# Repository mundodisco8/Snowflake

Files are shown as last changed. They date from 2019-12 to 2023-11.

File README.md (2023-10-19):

View this project on [CADLAB.io](https://cadlab.io/project/26393).

# Snowflake

A Snowflake Christmas decoration.
<p align="middle">
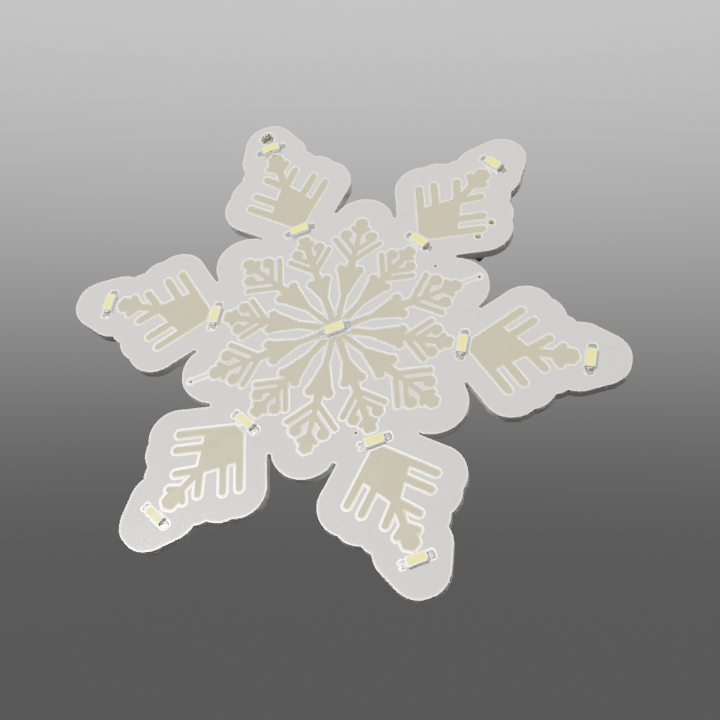
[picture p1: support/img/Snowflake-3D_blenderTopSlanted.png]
  
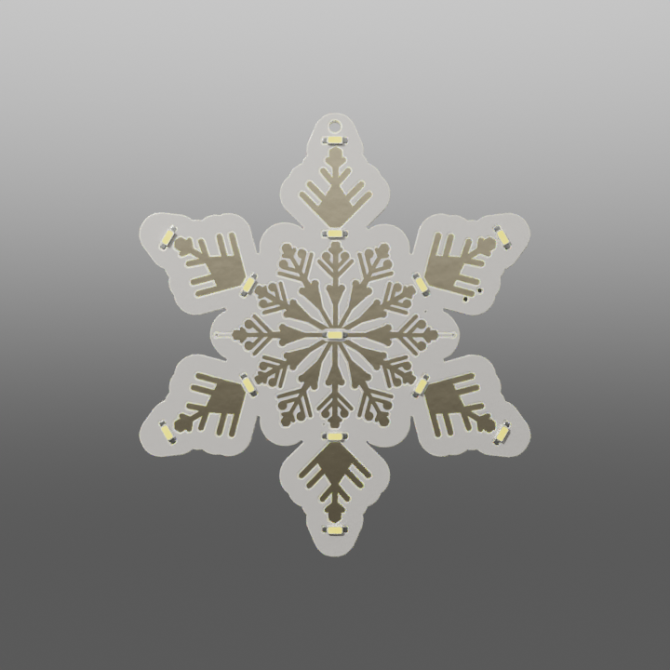
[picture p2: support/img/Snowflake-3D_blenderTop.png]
  
</p>

<p align="middle">
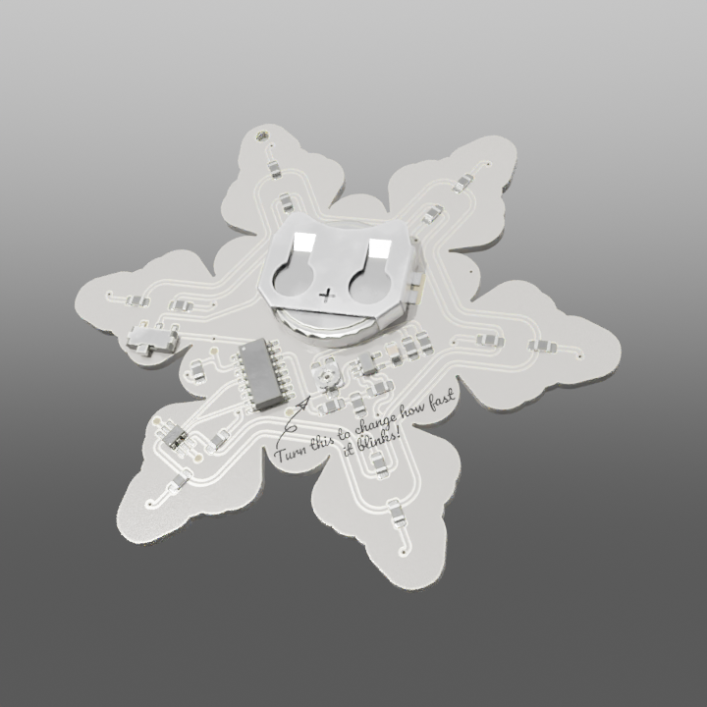
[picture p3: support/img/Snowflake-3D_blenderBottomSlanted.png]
  
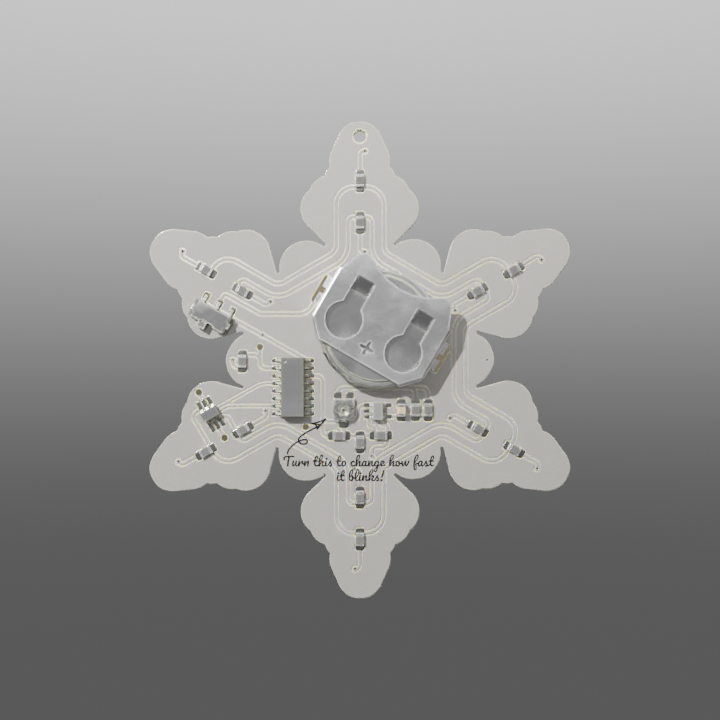
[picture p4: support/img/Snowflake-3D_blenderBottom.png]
  
</p>

Just a design exercise, aiming to get a hand-solderable board (although a bit challenging) that blinks its LEDs without using a microcontoller. I guess you can call it a mix of digital and analogue electronics, because the main trigger is a binary counter that is fed by a clock generated with an opamp in astable multivibrator config.

## Outputs

The outputs of this project can be found in the Releases area.

## Documentation

### Design Intention

You can find the design document in the [docs section](docs/Design%20Justification.ipynb), as a Jupyter notebook, or [better rendered here](https://mundodisco8.github.io/Snowflake), as a static rendering of the jupyter notebooks. For an interactive session, you can launch it on Binder if you want to play with the sliders.



You might even want to clone this repo and get your hands dirty. If you do, remember to create a virtual environment and install all the requirements.

```bash
python -m venv venv
venv/Scripts/Activate.bat # or source venv/bin/activate in Linux/Mac
python -m pip install -r requirements.txt
```

### Other bits and bobs

In the LTSpice folder you will find the circuits used on the Jupyter notebook to guess the current consumption as the battery discharges.

The `docs` folder also contains a couple of Excel spreadsheets I used to calculate some stuff, but they are not that interesting.

## Support Folder

The support folder contains random stuff that I needed at some point, mostly graphics.

I nicked the graphics from [here](https://svgsilh.com/image/2960229.html), which in turn is a variation of [this](https://pixabay.com/illustrations/snowflake-pattern-decor-decorative-2960229/).

## Running the CI/CD locally

The Release section only contains the artifacts of some hand-picked commits. Github Actions run on each commit on master, but the artifacts generated there have a self-life and get deleted after 15 days, I think. If you want, you can run the CICD pipeline locally.

```bash
# on the folder containing the project
# pull the KiBot image
docker pull ghcr.io/inti-cmnb/kicad7_auto_full:dev
# create a container named KiBotSnowDev, attaching the current folder as /Snowflake
docker run -it --name KiBotSnowDev -v .:/SnowFlake --entrypoint=/bin/bash ghcr.io/inti-cmnb/kicad7_auto_full:dev
# Now you are attached to the container
kibot -c ArtifactCreation.kibot.yaml -e hardware/Snowflake.kicad_sch -b hardware/Snowflake.kicad_pcb
```

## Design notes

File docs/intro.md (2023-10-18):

# Snowflake Interactive Documentation

This Jupyter Book contains the documentation of the project.

Check out the content pages bundled with this sample book to see more.

```{tableofcontents}
```

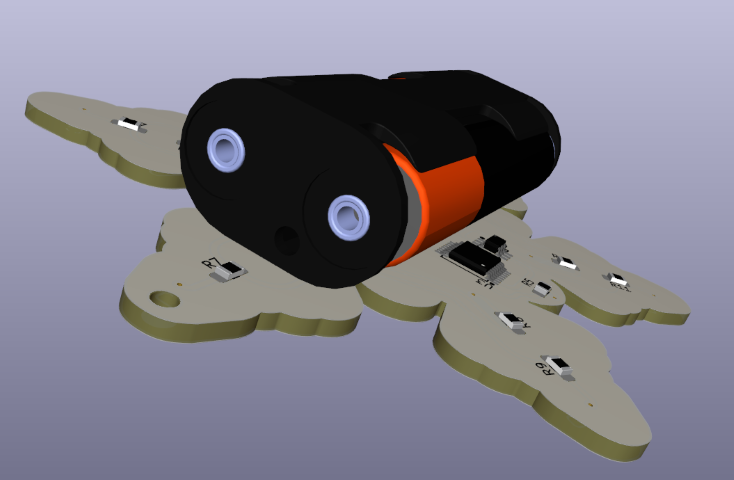
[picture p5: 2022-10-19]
img/AAA_On_PCB.png

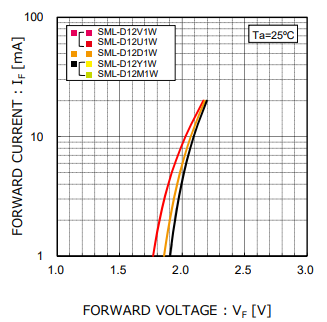
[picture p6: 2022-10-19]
img/Yellow_LED_Bias.png

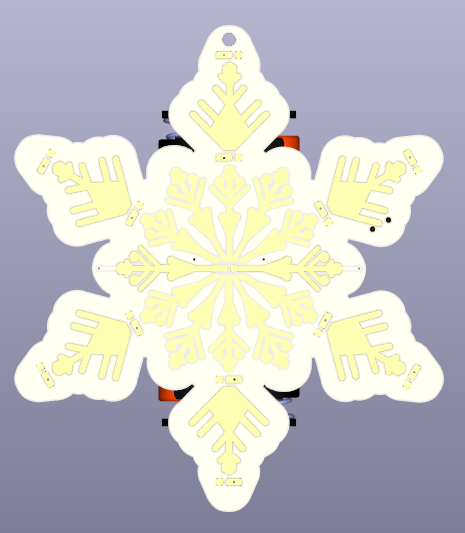
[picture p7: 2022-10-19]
img/AAA_On_PCB_Front.png

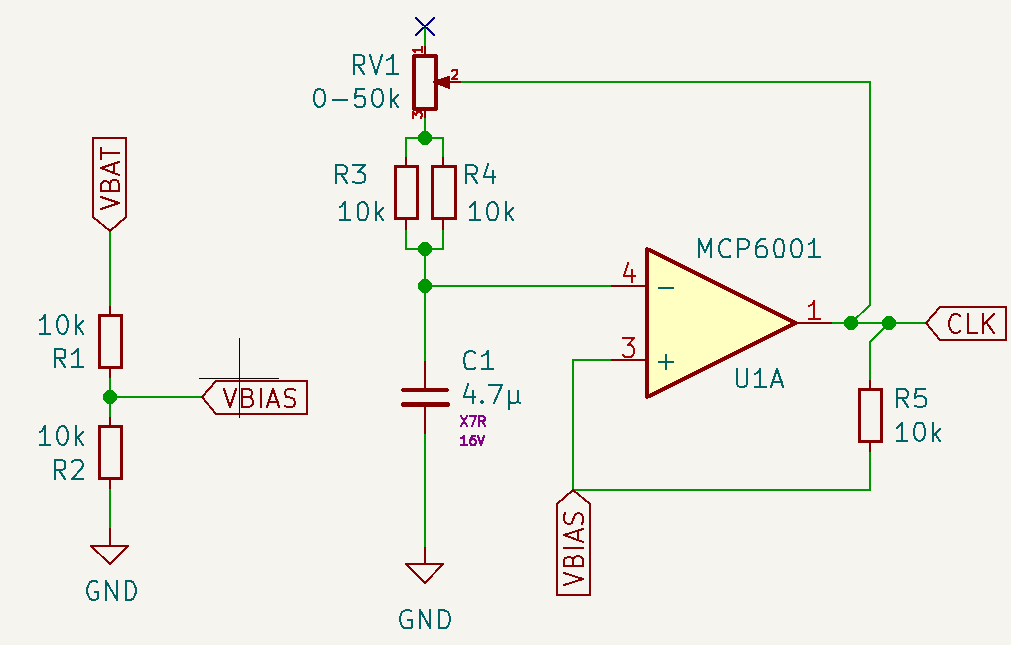
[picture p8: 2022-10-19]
img/Clock_With_Values.png

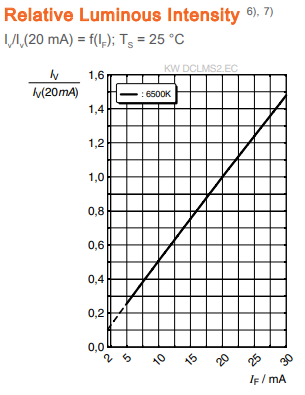
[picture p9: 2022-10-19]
img/KW_DCLMS2_LightvsCurr.png

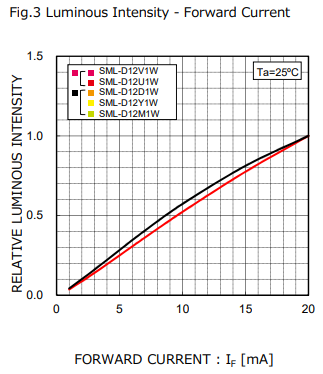
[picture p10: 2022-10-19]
img/Yellow_LED_LightvsCurr.png

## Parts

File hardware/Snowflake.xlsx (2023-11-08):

Prj: | Snowflake |  |  |  |  |  |  | Board Qty: | 12
Co.: |  |  |  |  |  |  |  | Unit Cost: | $6.97
Prj date: | 08/11/2023 13:36:20 |  |  |  |  |  |  | Total Cost: | $83.67 |  |  |  |  | $76.85 | 11 of 11 parts found
$ date: | 2023-11-08 13:36:46
Global Part Info |  |  |  |  |  |  |  |  |  | Digi-Key
Refs | Value | Footprint | Manf | Manf# | Tengo | Contingency | Qty | Unit$ | Ext$ | Avail | Purch | Unit$ | MOQ | Ext$ | Cat#
BT1 | CR2032 | CR2032_Keystone_3034 | Keystone Electronics | 3034 | 2 | 1 | 12 | $0.370 | $4.44 | 22324 | 11 | $0.370 | 1 | $4.07 | 36-3034-ND (https://www.digikey.com/en/products/detail/keystone-electronics/3034/4499289)
C1 | 4.7μ | 0805 | Murata | GRM21BR71C475KE51K | 12 |  | 12 |  |  | 86626 | 0 | $0.000 | 1 | $0.00 | 490-GRM21BR71C475KE51KCT-ND (https://www.digikey.com/en/products/detail/murata-electronics/GRM21BR71C475KE51K/8346263)
D1-D13 | White | 3014 | Osram | KWDCLMS2.EC-CXCZ-4L7M (https://dammedia.osram.info/media/resource/hires/osram-dam-16984996/KW%20DCLMS2.EC_EN.pdf) | 25 | 10 | 156 | $0.095 | $14.80 | 1122 | 141 | $0.095 | 1 | $13.38 | 475-KWDCLMS2.EC-CXCZ-4L7M-1-20-R18CT-ND (https://www.digikey.com/en/products/detail/ams-osram-usa-inc/KW-DCLMS2-EC-CXCZ-4L7M-1-20-R18/13679454)
Q1 | DMN2004DMK | SOT23-6 | Diodes Inc. | DMN2004DMK (https://www.diodes.com/assets/Datasheets/ds30937.pdf~) | 6 | 5 | 12 | $0.357 | $4.28 | 204723 | 11 | $0.357 | 1 | $3.93 | DMN2004DMKDICT-ND (https://www.digikey.com/en/products/detail/diodes-incorporated/DMN2004DMK-7/1287178)
R1-R5 | 10k | 0805 | Yageo | AF0805FR-0710KL | 50 | 10 | 60 | $0.054 | $3.24 | 26454 | 20 | $0.054 | 1 | $1.08 | 13-AF0805FR-0710KLCT-ND (https://www.digikey.com/en/products/detail/yageo/AF0805FR-0710KL/5901208)
R6-R18 | 56 | 0805 | Yageo | RC0805FR-1056RL | 28 | 10 | 156 | $0.013 | $1.98 | 21690 | 138 | $0.013 | 1 | $1.75 | 13-RC0805FR-1056RLCT-ND (https://www.digikey.com/en/products/detail/yageo/RC0805FR-1056RL/14286374)
RV1 | 0-50k | Potentiometer_TC33X-2-204E_NoSilk | Bourns Inc. | TC33X-2-503E (https://www.bourns.com/docs/Product-Datasheets/TC33.pdf) | 0 | 3 | 12 | $0.273 | $3.28 | 4117 | 15 | $0.273 | 1 | $4.10 | TC33X-503ECT-ND (https://www.digikey.com/en/products/detail/bourns-inc/TC33X-2-503E/612862)
SW1 | SPDT | Slider_Switch_C&K_AYZ0102AGRLC_SPDT_RightAngle_NoSilk | C&K | AYZ0102AGRLC (https://www.ckswitches.com/media/1431/ayz.pdf) | 2 | 1 | 12 | $1.204 | $14.45 | 9370 | 11 | $1.204 | 1 | $13.24 | 401-2012-1-ND (https://www.digikey.com/en/products/detail/c-k/AYZ0102AGRLC/1640108)
U1 | MCP6001T | SOT23-6 | Microchip | MCP6001T-I/OT (https://ww1.microchip.com/downloads/en/DeviceDoc/MCP6001-1R-1U-2-4-1-MHz-Low-Power-Op-Amp-DS20001733L.pdf) | 0 | 3 | 12 | $0.300 | $3.60 | 34720 | 15 | $0.300 | 1 | $4.50 | MCP6001T-I/OTCT-ND (https://www.digikey.com/en/products/detail/microchip-technology/MCP6001T-I-OT/551760)
U2#1 | HEF4017BT - p1/2 | 16-SOIC, 3.9x9.9mm, Pitch 1.27mm | Nexperia | HEF4017BT (https://assets.nexperia.com/documents/data-sheet/HEF4017B.pdf) | 1 | 3 | 12 |  |  | NonStk | 14 | MOQ=2500 | 2500 |  | 1727-HEF4017BT-Q100JTR-ND (https://www.digikey.com/en/products/detail/nexperia-usa-inc/HEF4017BT-Q100J/5169993)
U2#2 | HEF4017BT - p2/2 | 16-SOIC, 3.9x9.9mm, Pitch 1.27mm | Nexperia | 653 (https://assets.nexperia.com/documents/data-sheet/HEF4017B.pdf) | 1 |  | 12 | $2.800 | $33.60 | 1914 | 11 | $2.800 | 1 | $30.80 | 36-653-ND (https://www.digikey.com/en/products/detail/keystone-electronics/653/316566)
 |  |  |  |  |  |  |  | Total Purchase: | $76.85 | Buy here (https://www.digikey.com/ordering/shoppingcart) | 10 of 11 parts purchased |  |  | $76.85
KiCost® v1.1.18 |  |  |  |  |  |  |  | Purchase description: |  |  | 11,36-3034-ND,BT1 141,475-KWDCLMS2.EC-CXCZ-4L7M-1-20-R18CT-ND,D1-D13 11,DMN2004DMKDICT-ND,Q1 20,13-AF0805FR-0710KLCT-ND,R1-R5 138,13-RC0805FR-1056RLCT-ND,R6-R18 15,TC33X-503ECT-ND,RV1 11,401-2012-1-ND,SW1 15,MCP6001T-I/OTCT-ND,U1 11,36-653-ND,U2#2

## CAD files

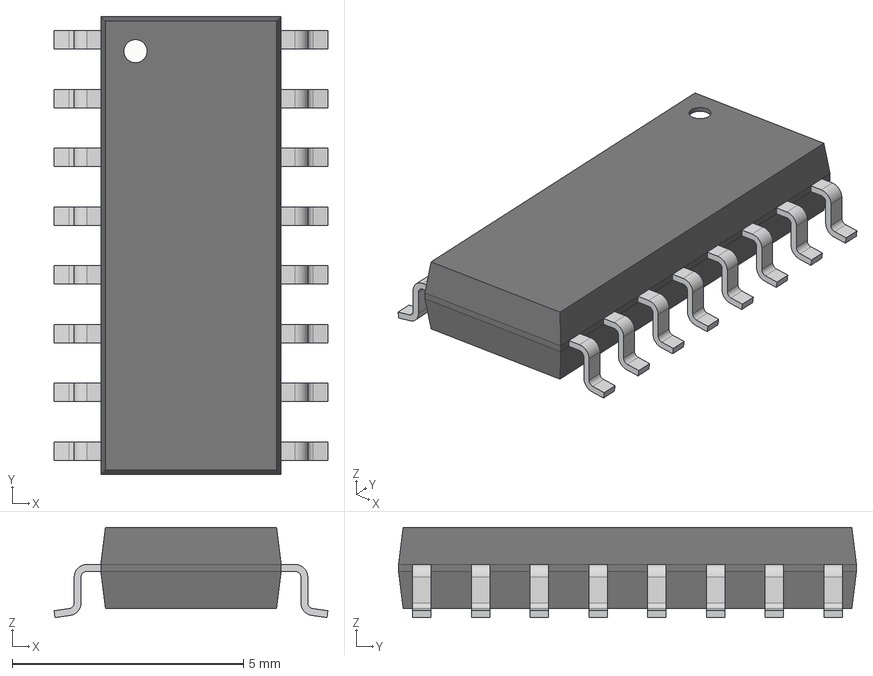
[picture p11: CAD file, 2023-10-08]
hardware/Snowflake_library/3D_Models/16-SOIC Narrow 4x9.9mm Pitch 1.27mm.step
5.92 x 9.90 x 1.95 mm
Single Pin x 8
Single Pin(Mirror) x 8

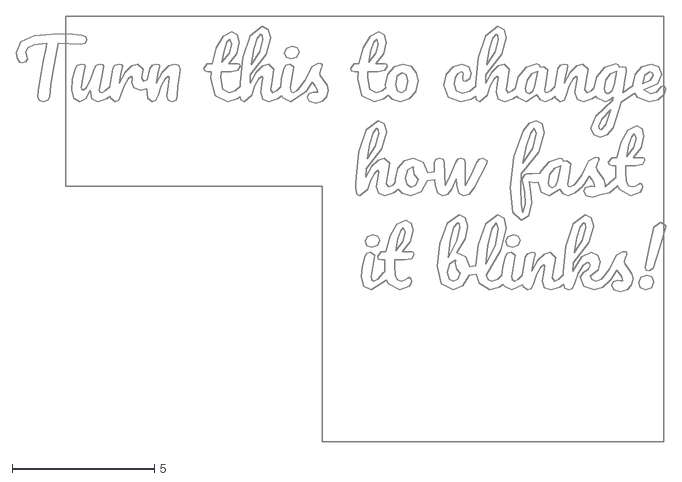
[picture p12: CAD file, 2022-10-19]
support/Graphics/Silkscreen - Turn this/Text - Turn this.dxf
22.9 x 15.0

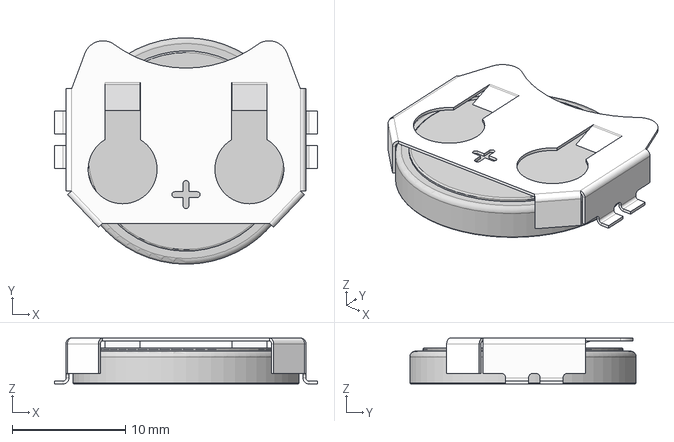
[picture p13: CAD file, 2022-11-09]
hardware/Snowflake_library/3D_Models/Battery Holder - CR2032 - Keystone - 3034 - With Battery v4.step
23.2 x 20.0 x 4.06 mm

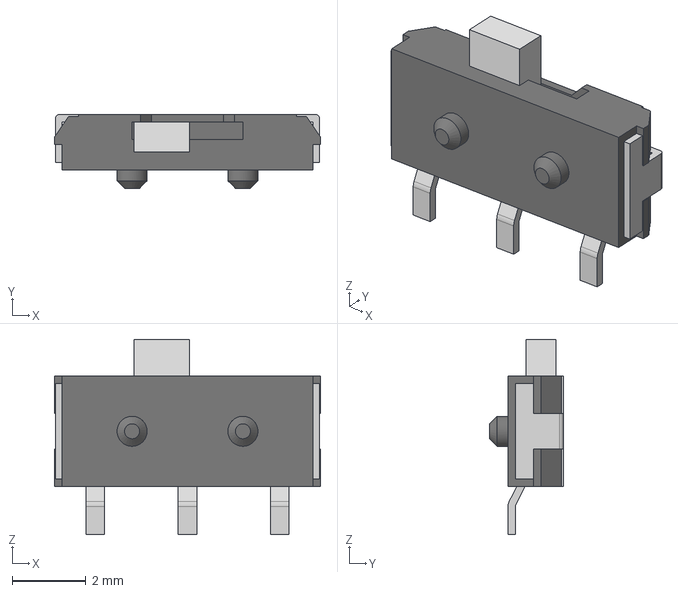
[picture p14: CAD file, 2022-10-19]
hardware/Snowflake_library/3D_Models/Switch - Slider - SPDT Right Angle - AYZ0102AGRLC - C&K v2.step
7.20 x 2.00 x 5.29 mm

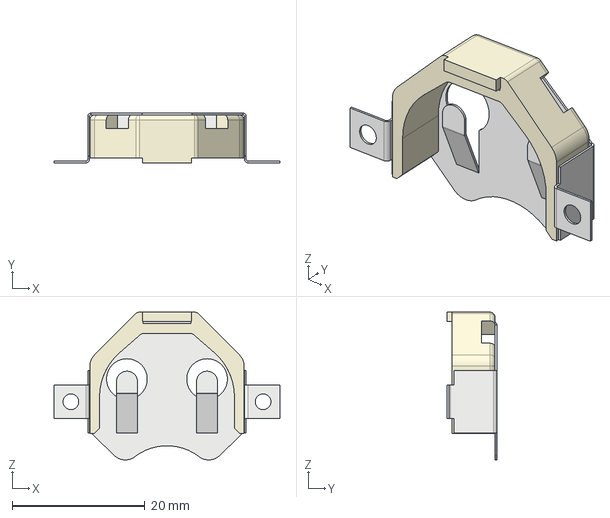
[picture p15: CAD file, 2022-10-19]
hardware/Snowflake_library/3D_Models/Battery Holder - CR2032 x2 - Keystone - 3074-2 v3.step
34.0 x 7.49 x 22.3 mm
Battery Holder

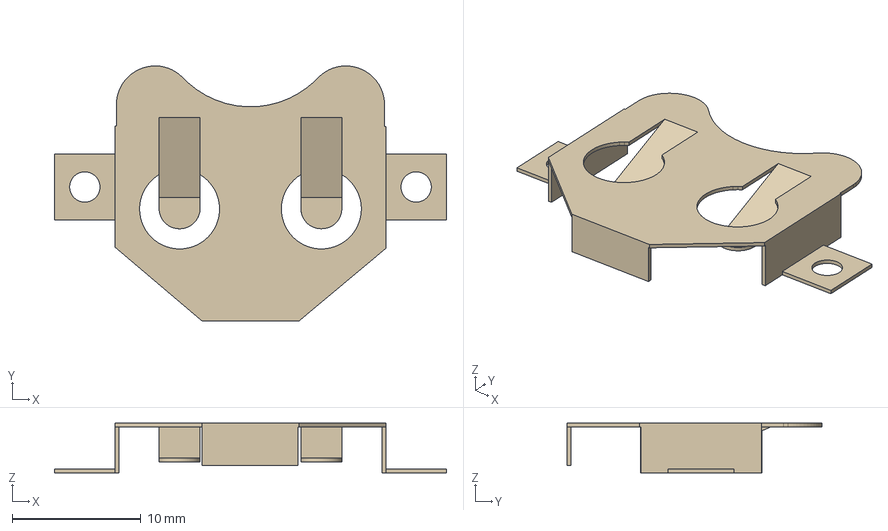
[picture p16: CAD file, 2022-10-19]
hardware/Snowflake_library/3D_Models/Battery Holder - CR2032 - Multicomp MP000357 v5.step
30.4 x 19.8 x 3.85 mm

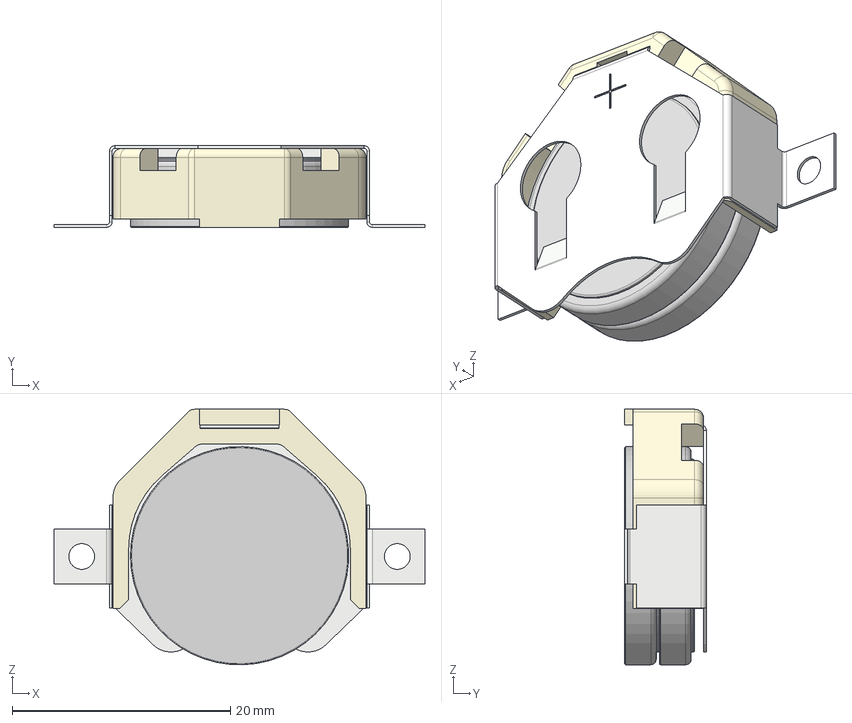
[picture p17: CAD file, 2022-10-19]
hardware/Snowflake_library/3D_Models/Battery Holder - CR2032 x2 - With Battery - Keystone - 3074-2 v2.step
34.0 x 7.49 x 23.4 mm
Battery - CR2032 x 2
Battery Holder

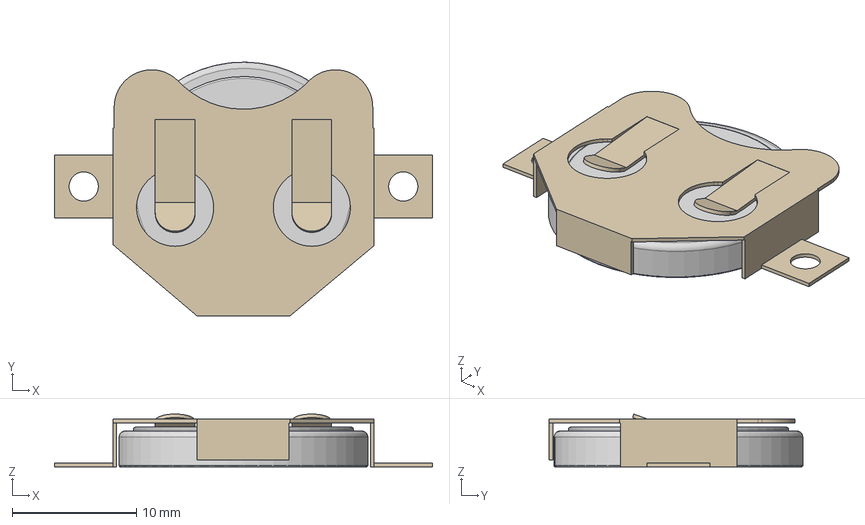
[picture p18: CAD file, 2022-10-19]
hardware/Snowflake_library/3D_Models/Battery Holder - CR2032 - With Battery - Multicomp MP000357 v7.step
30.4 x 20.4 x 4.26 mm
Battery Pins
Battery - CR2032

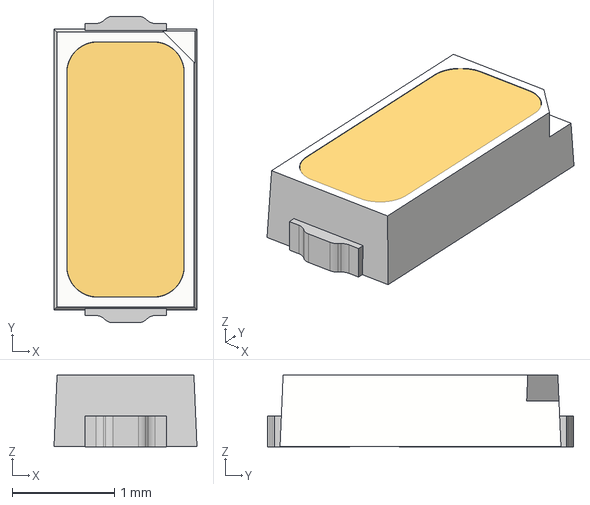
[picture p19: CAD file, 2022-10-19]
hardware/Snowflake_library/3D_Models/1206 - LED -3.0x1.4mm v1.step
1.40 x 3.00 x 0.7 mm

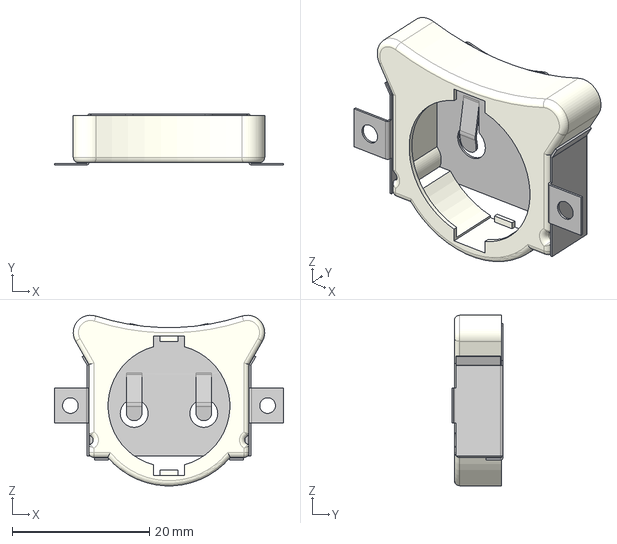
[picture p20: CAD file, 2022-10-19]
hardware/Snowflake_library/3D_Models/Battery Holder - CR2032 x2 - BHX2-2032-SM v2.step
33.4 x 7.49 x 24.9 mm
BHX2-2032-SM sheetmetal
BHX2-2032-SM insulator

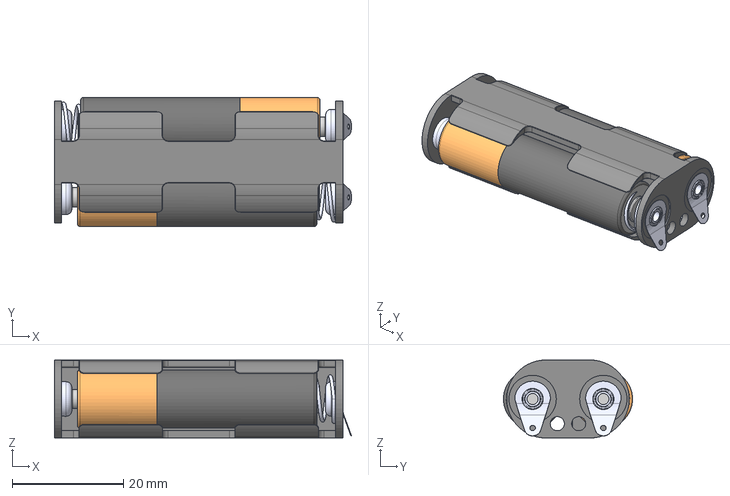
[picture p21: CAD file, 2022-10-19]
hardware/Snowflake_library/3D_Models/Battery Holder - 2xAAA - MCP BC22AAAL v2.step
53.3 x 23.2 x 14.0 mm
Battery - AAA x 2

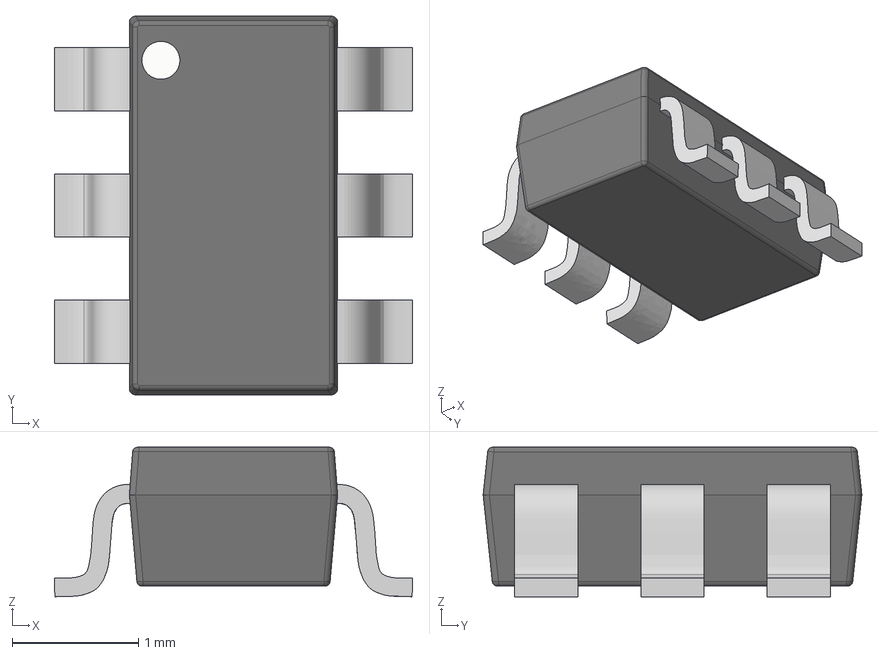
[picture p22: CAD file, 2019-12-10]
hardware/Snowflake_library/3D_Models/SOT23-6 v7.step
2.84 x 3.00 x 1.18 mm

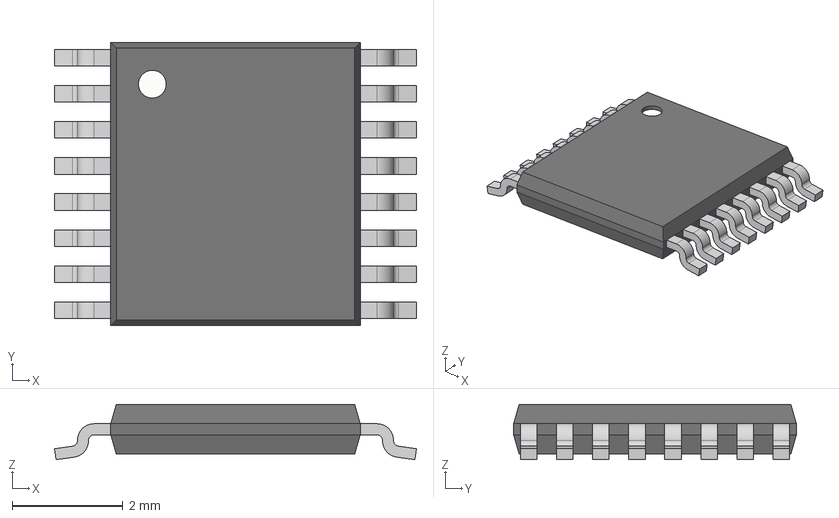
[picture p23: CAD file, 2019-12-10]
hardware/Snowflake_library/3D_Models/16-TSSOP 5x4.4x1mm .65mm Pitch v2.step
6.53 x 5.10 x 0.999 mm
Single Pin x 8
Single Pin(Mirror) x 8

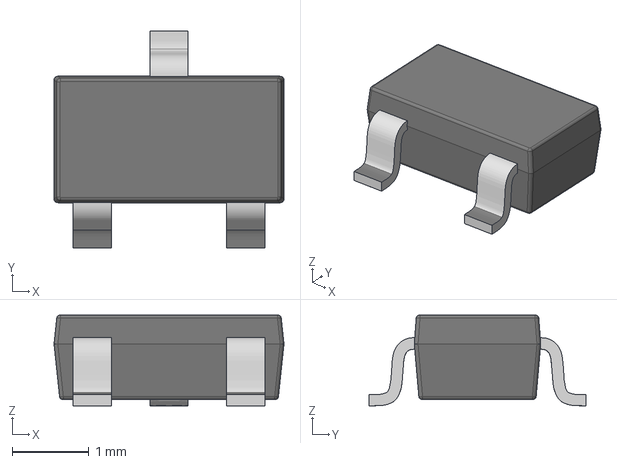
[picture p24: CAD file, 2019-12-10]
hardware/Snowflake_library/3D_Models/SOT23-3 v3.step
3.00 x 2.84 x 1.18 mm

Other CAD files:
hardware/Snowflake_library/3D_Models/SOT23-5 v2.step
hardware/Snowflake_library/3D_Models/14-SOIC Narrow 4x8.75x1.75mm Pitch 1.27mm v3.step
hardware/Snowflake_library/3D_Models/TC-33X-2 v2.step
hardware/Snowflake_library/3D_Models/0606 - LED - 1.6x1.5mm v3.step
hardware/Snowflake_library/3D_Models/0603 - LED v2.step
hardware/Snowflake_library/3D_Models/Capacitor SMD 0805.step
hardware/Snowflake_library/3D_Models/JS202011SCQN v2.step
hardware/Snowflake_library/3D_Models/Resistor SMD 0805.step

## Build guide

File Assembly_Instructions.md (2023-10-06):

# Demo population with filters

By following this build order, it's relatively easy to test the different modules in the circuit in isolation, minimising the risk of building the PCB. Obviously a scope and a multimeter will be handy, but the board can be effectively troubleshot with a throughole LED, so I recommend getting one from the spare parts box.

- [[front | ]] This is the front side of the board we are populating
- [[back | ]] This is the back side of the board we are populating
- [[back | _kf(clock)]] First, populate the clock generation, OpAmp, 10KΩ resistors, cap and pot.
- [[back | BT1, SW1]] Then add the switch and the battery, so the battery clip is not on the way when soldering the OpAmp.
- When the clock generation is placed, you can test it works properly. Connect the cathode of a diode to pin 1 of U1 and the anode to GND (for example, the "bottom" pad of R2). The LED must blink. Turning the potentiometer RV1 should change the blink period.
- [[back | Q1, R6, R11, R12]] Now let's move to the switching. Place the transistor Q1 and the current limiting resistors for the centre LED and one of the stems of the snowflake (R11, R12).
- [[front | D1, D6, D7]] Now place some LEDs to test the transistor is working. Seems obvious, but make sure you populate the LEDs corresponding to the current-limiting resistors you just placed! Before soldering D1, I recommend placing some Kapton tape around the pad, to protect the exposed art around it. Otherwise, unless you are incredibly skilled, you risk dropping a blob of solder around it, and it will look rather messy and ugly. The same can be said about the rest of the LEDs, but the risk is lower, and just by being careful, you can avoid messing it up!. Be careful, those LEDs are delicate!
- With this, you can either use a jumper cable to connect the output of the opamp (pin 1 in U1) to the gates of the transistors (pins 2 and 5 of Q1) and the "top" pad of R6. The LEDs should blink (the opamp should provide enough current for D1, don't worry). Alternatively, you can connect the gates or the top pad of R6 to VCC to switch them LEDs on.
- [[back | U2]] Place the binary counter. This is tricky, as it's easy to sort the pins, so make sure the chip is well aligned on the footprint, and add lots of flux.
- After this, you board is more or less fully functional. Switching it on should trigger the alternate blinking of the three LEDs already placed. If this doesn't work, then there must be a problem with your counter.
- [[back | _kf(currentResistors)]] Place the remaining current limiting resistors (nearly there)...
- [[front | _kf(LEDs)]] ... and the remaining current LEDs.

And here is the finished board

- [[back | ]] Back, fully assembled.
- [[front | ]] Front, ready to blink.

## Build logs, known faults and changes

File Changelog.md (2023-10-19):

# CHANGELOG

## v2.0.0-RC1

General improvements after building the first batch. The main change is the replacement of the decade counter package with a SOIC-16 from a TSSOP-16. It's a bit uglier, but it's easier to solder and it was the main source of issues on the first batch.

### Added

- Fancy CI/CD with KiBot
- Published the documentation as a webpage.

### Changed

- Changed the decade counter package to SOIC-16. I ordered them by mistake and while they are chunky, the previous one (TSSOP-16) was a source of issues while soldering without magnification (these poor eyes...).
- Rotated the Battery holder so replacing the battery is a bit easier. It also avoids the battery hitting one of the current limiter resistors and knocking it out
- F.Fab is a tad neater.
- Added test points to help during assembly.
- Extended some footprints to help with hand assembly.

## v1.0.0

### Added

- First Release.

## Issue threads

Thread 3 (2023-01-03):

LED Footprint

mundodisco8, 2023-01-03:
LED footprints are really tight and soldering is difficult

Closed 2023-10-19.

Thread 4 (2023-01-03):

Rotate the battery holder

mundodisco8, 2023-01-03:
As it is, one of the current limiting resistors will hit the battery when removing it, making it a bit difficult to remove. Maybe rotating the footprint 30° will leave enough clearance for the battery to slide free

mundodisco8, 2023-10-06:
Done

Closed 2023-10-06.

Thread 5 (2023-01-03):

Counter footprint: tweak or replace

mundodisco8, 2023-01-03:
It's a bloody pain to solder, at least without magnification. I think the pads are a tad too wide, and they could be longer too.
In any case, by mistake I ordered a part I thought it was equivalent and came in SOIC footprint. It's much bigger, but it leaves more space between pins. Consider changing to that part

mundodisco8, 2023-10-06:
Replaced with the SOIC16, it's ugly, but makes things easier

Closed 2023-10-06.

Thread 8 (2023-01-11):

counter part name is incorrect

mundodisco8, 2023-01-11:

mundodisco8, 2023-10-06:
Nexperia has the HEF4017BT,653, which I think it's pin compatible with the CD4017BPWR, which is the one I used. Make sure, or change the schematic accordingly if not

mundodisco8, 2023-10-07:
We are leaving the HEF

Closed 2023-10-07.

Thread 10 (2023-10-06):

Test points

mundodisco8, 2023-10-06:
During the assembly, it is useful to have a bunch of test points to poke around and make sure everything is working.

Get test pads for:
* Clock output -> CLK Signal, output of the opamp
* Two gates of the dual NMOS
* LED0 pin on the binary counter

Closed 2023-10-19.

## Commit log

2019-11-14 First Commit Schematic is enough to start working. Need to add power
    [LED_Stem.sch, LED_Stemsch.sch, Snowflake.kicad_pcb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]
2019-11-15 Added battery holders
    [LED_Stem.sch, Snowflake.sch]
2019-12-03 Added the Snowflake part to the library
    [LED_Stem.sch, Snowflake.kicad_pcb, Snowflake.sch]
2019-12-06 Schematic 99%, just needs a couple of tweaks (assign footprints to the OpAmp and the switch) Added a bunch of 3D models and footprints
    [0603 - LED v2.step, 0606 - LED - 1.6x1.5mm v3.step, Capacitor SMD 0805.step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]
2019-12-06 Terayza new parts added and some layout started
    [LED_Stem.sch, Snowflake.kicad_pcb, Snowflake.sch]
2019-12-10 Terayza changes
    [LED_Stem.sch, Snowflake.kicad_pcb, Snowflake.sch]
2019-12-10 All footprints in place, schematic done
    [14-SOIC Narrow 4x8.75x1.75mm Pitch 1.27mm v3.step, 16-TSSOP 5x4.4x1mm .65mm Pitch v2.step, JS202011SCQN v2.step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]
2019-12-11 Still leaft to connect: Vbat from all the LEDs
    [Snowflake.kicad_pcb]
2019-12-11 A bit of tidying up in the PCB.
    [Snowflake.kicad_pcb, Snowflake.sch]
2020-01-14 Rerouter the tracks in 30 degrees
    [Snowflake.kicad_pcb, Snowflake.sch]
2020-01-14 Added some files to the support folder
    [Snowflake.kicad_pcb]
2022-09-16 Updated the Design to KiCad6 and made the track corners rounded
    [LED_Stem.kicad_sch, Snowflake.kicad_pcb, Snowflake.kicad_sch]
2022-09-20 Updated Symbol Library to KiCad 6 Removed Silk from LEDs on front Added six extra pads to the snowflake
2022-09-20 Fixed a bug, where I was sorting all the LEDs :S Removed all DRC rules Ready to fillet tracks
    [LED_Stem.kicad_sch, Snowflake.kicad_pcb, Snowflake.kicad_sch]
2022-09-20 Rounded the tracks!
    [Snowflake.kicad_pcb, Snowflake.kicad_sch]
2022-10-03 Discarded the idea of using AAA batteries and switched to CR2032s
    [1206 - LED -3.0x1.4mm v1.step, Battery Holder - 2xAAA - MCP BC22AAAL v2.step, Battery Holder - CR2032 - Multicomp MP000357 v5.step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]
2022-10-12 Pre-test push. Happy with the layout, waiting for the tests to choose an LED, resitor and battery holder
    [LED_Stem.kicad_sch, Snowflake.kicad_pcb, Snowflake.kicad_sch]
2022-10-19 Happy with the HW
    [Battery Holder - CR2032 x2 - BHX2-2032-SM v2.step, Battery Holder - CR2032 x2 - Keystone - 3074-2 v3.step, Battery Holder - CR2032 x2 - With Battery - Keystone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]
2022-10-19 Documentation in a Jupyter Notebook
    [Cap Calculations.xlsx, Cap Charging time.xlsx, Text - Turn this.dxf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]
2022-11-09 Updated footprint for LED as it was a bit off and changed to a single CR2032 holder that's quite compact
    [Battery Holder - CR2032 - Keystone - 3034 - With Battery v4.step, LED_Stem.kicad_sch, Snowflake.kicad_pcb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]
2022-11-09 Configured KIBoM as BoM manager
2022-11-09 Changed a couple of parts to alternatives that are more available AND cheaper
    [LED_Stem.kicad_sch, Snowflake.kicad_pcb, Snowflake.kicad_sch]
2022-11-09 The switch had lost its 3D Model
    [Snowflake.kicad_pcb]
2023-01-06 v1.0.0 First manufactured version Updated gitignore and removed a bunch of virtualenv files Tweaked some footprints Added farnell PN, MPNs, etc.
    [LED_Stem.kicad_sch, LED_Stem.sch, LED_Stemsch.sch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]
2023-01-06 Added a reference to the silkscreen element (it was the default REF**)
    [Snowflake.kicad_pcb]
2023-01-10 Fixed some DRCs introduced on KiCad 6.0.10 (changes in the PWR symbol library)
    [Snowflake.kicad_pcb, Snowflake.kicad_sch]
2023-01-11 Added some text to the sheet to commit hash and date printed on the outputs
    [LED_Stem.kicad_sch, Snowflake.kicad_pcb, Snowflake.kicad_sch]
2023-01-11 first commit with github actions
    [LED_Stem.kicad_sch, Snowflake.kicad_pcb, Snowflake.kicad_sch]
2023-01-12 CICD is working on Github, last touches to files before work on v1.1.0 starts
    [LED_Stem.kicad_sch, Snowflake.kicad_pcb, Snowflake.kicad_sch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]
2023-01-27 Added Assembly Instructions output
2023-10-06 Some changes in the project to get it to pass in the latest KiBot docker image
    [LED_Stem.kicad_sch, Snowflake.kicad_pcb, Snowflake.kicad_sch]
2023-10-08 Changed the Counter footprint to 16-SOIC
    [16-SOIC Narrow 4x9.9mm Pitch 1.27mm.step, LED_Stem.kicad_sch, Snowflake.kicad_pcb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]
2023-10-12 Updated CI/CD, split config in multiple files so it's easy to keep track of everything Added an action that updates the images used in the readme and pushes them back to the repo.
    [Snowflake.kicad_pcb]
2023-10-17 remove whitespaces just in case
2023-10-19 Closed remaining issues in Github (#10, #7, #6, #3) * Tweaked the SOT23-6 footprint * Tweaked the rotary pot footprint * Tweaked the LED footprint * Added some testpoints
    [Snowflake.kicad_pcb, Snowflake.kicad_sch]
2023-10-19 Fixed errors on CICD
    [Snowflake.kicad_pcb, Snowflake.kicad_sch]
2023-11-08 Added some stuff missing from the BoM Changed the LED component name from 4014 to 3014 (typo). Updated schematic and board
    [LED_Stem.kicad_sch, Snowflake.kicad_pcb, Snowflake.kicad_sch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]
